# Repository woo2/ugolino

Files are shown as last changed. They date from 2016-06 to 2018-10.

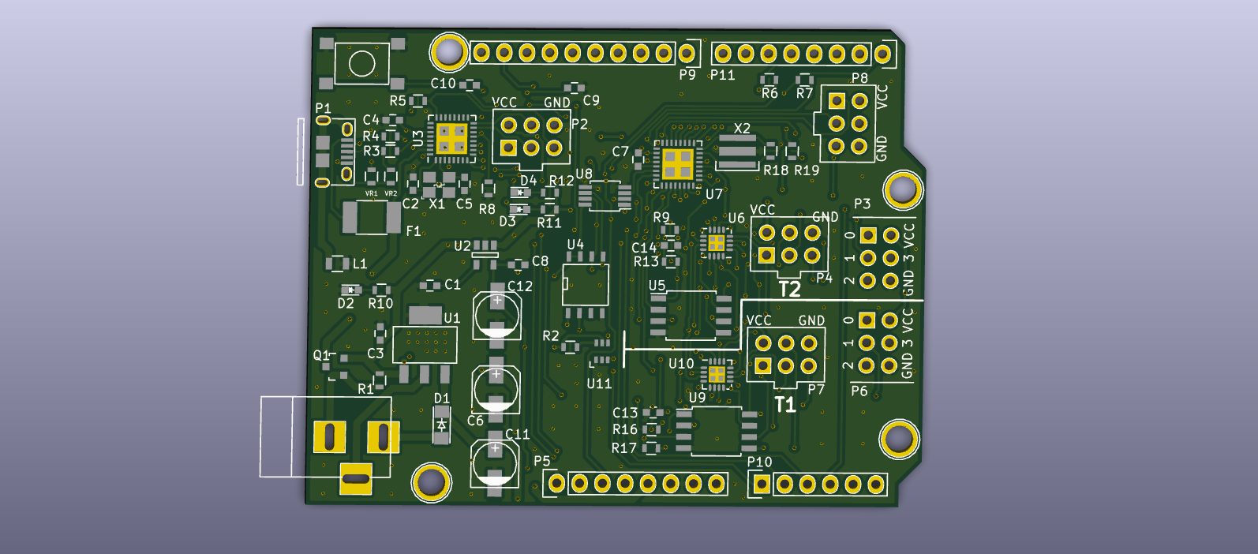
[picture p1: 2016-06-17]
hw/dev-board.png

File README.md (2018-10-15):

# The Ugolino
An Arduino compaible board based on the ATMEGA328PB that uses the secondary SPI
bus provided by the 328 to interface with 256k of SRAM. There are two aditional
AVRs on borad, both are ATTINY85 microcontrollers. The 85s share the SRAM with
the 328. The 85s' each have four GPIO pins broken out. In order to implement
this functionality, bus switches were used to multiplex the SPI bus and GPIO of
each 85.

An ATMEGA16u2 was used as a USB to serial tranceiver. Right now, support for the
328pb is limited, a patch for the pb is needed for avrdude, and the Arduino IDE
requires an extra board to be installed.

## Known Issues
* ~MISO and MOSI on the Tinys are labeled with respect to the host, where the
tiny is a slave.~(fixed)
* ~SS_328 is not connected to the SS line of the RAM.~ (fixed)
* The PCB does not yet reflect the changes marked fixed.
corrected.

## How to put code on the 328PB

1. Flash the U2:

  Running parts 1 and 2 together did not work for me. It could be that the fuses need to be written before the flash can be programmed properly. Use the same command up to the ```-U``` in part 1 for part 2.
  1. ```sudo avrdude -p m16u2 -c usbtiny -U lfuse:w:0xFF:m -U hfuse:w:0xD9:m -U efuse:w:0xF4:m -U lock:w:0x0F:m -v```
  2. ```flash:w:/home/paul/.arduino15/packages/arduino/hardware/avr/1.6.11/firmwares/atmegaxxu2/arduino-usbserial/Arduino-usbserial-atmega16u2-Uno-Rev3.hex```

2. Right now, the 328pb is not supported by avrdude. To fix this, put
[this](https://savannah.nongnu.org/bugs/?48237) snippet in your
`/etc/avrdude.conf` file. A copy of the fixed file is included. If you trust
me, run `sudo cp avrdude.conf /etc/avrdude.conf` in the root of this repo.

The Ugolino was first created as an intern project while I was working at
[Thimble.io](http://thimble.io), and I have recieved permission to publish this
work publicly.

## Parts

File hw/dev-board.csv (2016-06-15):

Reference | Quantity | Value | Footprint | Datasheet | Part Number
C1 | 1 | 470pF | Capacitors_SMD:C_0603
C10 | 1 | 100n | Capacitors_SMD:C_0603
C12 | 1 | 10uF | Capacitors_SMD:c_elec_5x5.3
C2 C5 | 2 | 15pf | Capacitors_SMD:C_0603
C4 | 1 | 1uF | Capacitors_SMD:C_0603
C11 C6 | 2 | 47uF | Capacitors_SMD:c_elec_5x5.3
C13 C14 C3 C7 C8 C9 | 6 | .1uF | Capacitors_SMD:C_0603
CON1 | 1 | BARREL_JACK | Connect:BARREL_JACK
D1 | 1 | D | GenericTransistorsFoots:SMD_Diode-1206
D2 D3 D4 | 3 | LED | LEDs:LED_0603
F1 | 1 | 500m | Resistors_SMD:R_1812
L1 | 1 | Inductor | Resistors_SMD:R_0805
P1 | 1 | USB_OTG | Spenduino_CustomFootprints:USB_Micro-B_10118194
P10 | 1 | CONN_01X06 | Pin_Headers:Pin_Header_Straight_1x06
P11 P5 | 2 | CONN_01X08 | Pin_Headers:Pin_Header_Straight_1x08
P3 P6 | 2 | CONN_02X03 | pcbfp_lib:Pin_Header_Straight_2x03_ATTINY
P2 P4 P7 P8 | 4 | CONN_02X03_ICSP | pcbfp_lib:Pin_Header_Straight_2x03_ICSP
P9 | 1 | CONN_01X10 | Pin_Headers:Pin_Header_Straight_1x10
Q1 | 1 | FDN340P | TO_SOT_Packages_SMD:SOT-23
R18 | 1 | 1M | Resistors_SMD:R_0603
R2 | 1 | 1K
R3 R4 | 2 | 22R | Resistors_SMD:R_0603
R1 R13 R16 R17 R19 R5 R9 | 7 | 10K | Resistors_SMD:R_0603
R10 R11 R12 R6 R7 R8 | 6 | 1K | Resistors_SMD:R_0603
SW1 | 1 | SW_PUSH | GenericTransistorsFoots:PTS645_Button_SMT
U1 | 1 | LM2940LD-5.0 | pcbfp_lib:SOT-223
U11 | 1 | FDG6331L | TO_SOT_Packages_SMD:SC-70-6
U2 | 1 | MIC5205 | TO_SOT_Packages_SMD:SOT-23-5
U3 | 1 | ATMEGA16U2 | Housings_DFN_QFN:QFN-32-1EP_5x5mm_Pitch0.5mm | http://www.atmel.com/Images/doc7799.pdf
U4 | 1 | 23K256 | SMD_Packages:SOIC-8-N
U5 U9 | 2 | ATTINY85-SUR | Housings_SOIC:SOIJ-8_5.3x5.3mm_Pitch1.27mm
U10 U6 | 2 | TS3A44159 | Housings_DFN_QFN:QFN-16-1EP_3x3mm_Pitch0.5mm
U7 | 1 | ATMEGA328PB-MU | Housings_DFN_QFN:QFN-32-1EP_5x5mm_Pitch0.5mm
U8 | 1 | 74LVCH1T45 | Housings_SSOP:MSOP-8_3x3mm_Pitch0.65mm
VR1 VR2 | 2 | VR | Resistors_SMD:R_0603
X1 | 1 | CRYSTAL | Spenduino_CustomFootprints:SMD_Crystal_ABM8G
X2 | 1 | RESONATOR | Spenduino_CustomFootprints:AWSCR-CV_Resonator

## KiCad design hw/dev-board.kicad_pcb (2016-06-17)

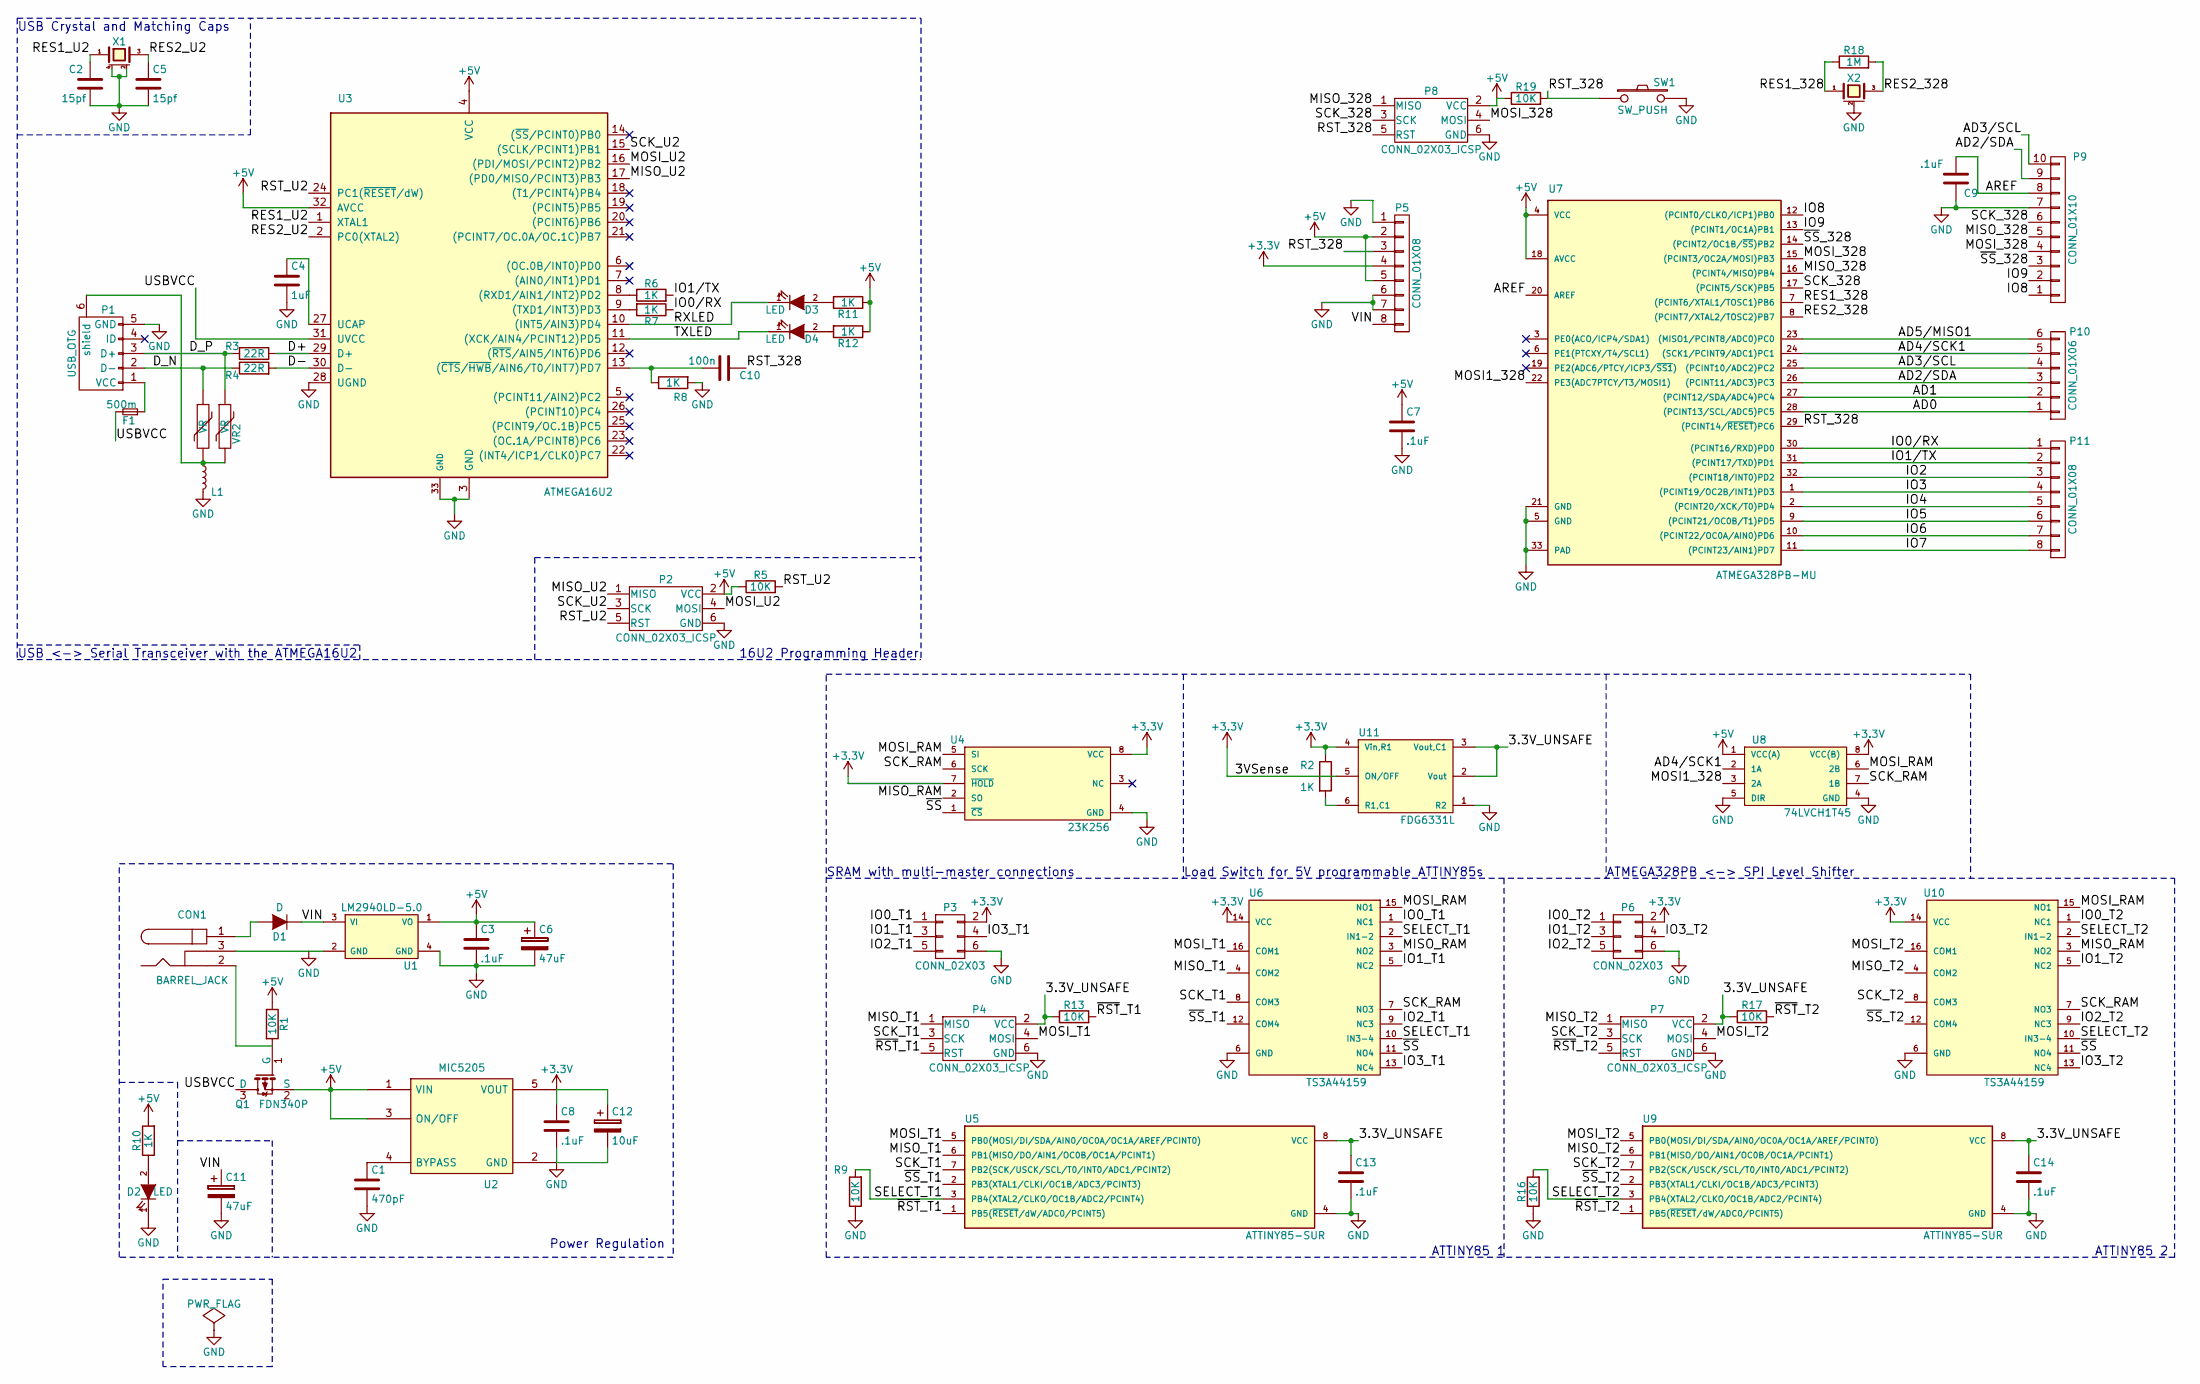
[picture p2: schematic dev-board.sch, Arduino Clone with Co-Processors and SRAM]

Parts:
C1: 470pF; C_0603
C2, C5: 15pf; C_0603
C3, C7, C8, C9, C13, C14: .1uF; C_0603
C4: 1uF; C_0603
C6, C11: 47uF; c_elec_5x5.3
C10: 100n; C_0603
C12: 10uF; c_elec_5x5.3
CON1: BARREL_JACK
D1: D; SMD_Diode-1206
D2, D3, D4: LED; LED_0603
F1: 500m; R_1812
L1: Inductor; R_0805
P1: USB_OTG; USB_Micro-B_10118194
P2, P4, P7, P8: CONN_02X03_ICSP; Pin_Header_Straight_2x03_ICSP
P3, P6: CONN_02X03; Pin_Header_Straight_2x03_ATTINY
P5, P11: CONN_01X08; Pin_Header_Straight_1x08
P9: CONN_01X10; Pin_Header_Straight_1x10
P10: CONN_01X06; Pin_Header_Straight_1x06
Q1: FDN340P; SOT-23
R1, R5, R9, R13, R16, R17, R19: 10K; R_0603
R2, R6, R7, R8, R10, R11, R12: 1K; R_0603
R3, R4: 22R; R_0603
R18: 1M; R_0603
SW1: SW_PUSH; PTS645_Button_SMT
U1: LM2940LD-5.0; SOT-223
U2: MIC5205; SOT-23-5
U3: ATMEGA16U2; QFN-32-1EP_5x5mm_Pitch0.5mm
U4: 23K256; SOIC-8-N
U5, U9: ATTINY85-SUR; SOIJ-8_5.3x5.3mm_Pitch1.27mm
U6, U10: TS3A44159; QFN-16-1EP_3x3mm_Pitch0.5mm
U7: ATMEGA328PB-MU; QFN-32-1EP_5x5mm_Pitch0.5mm
U8: 74LVCH1T45; MSOP-8_3x3mm_Pitch0.65mm
U11: FDG6331L; SC-70-6
VR1: VR; R_0603
VR2: VR; R_0603; Part Number CG0603MLC-05E1
X1: CRYSTAL; SMD_Crystal_ABM8G
X2: RESONATOR; AWSCR-CV_Resonator

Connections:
+3V3: C8.1, C12.1, P3.2, P5.4, P6.2, R2.1, U2.5 (VOUT), U4.7 (~HOLD), U4.8 (VCC), U6.14 (VCC), U8.8 (VCC(B)), U10.14 (VCC), U11.4 (Vin,R1), U11.5 (ON/OFF)
+5V: C3.1, C6.1, C7.1, P2.2 (VCC), P5.2, P5.5, P8.2 (VCC), Q1.2 (S), R1.1, R5.1, R10.2, R11.1, R12.1, R19.1, U1.1 (VO), U2.1 (VIN), U2.3 (ON/OFF), U3.4 (VCC), U3.32 (AVCC), U7.4 (VCC), U7.18 (AVCC), U8.1 (VCC(A))
/3.3V_UNSAFE: C13.1, C14.1, P4.2 (VCC), P7.2 (VCC), R13.1, R17.1, U5.8 (VCC), U9.8 (VCC), U11.2 (Vout), U11.3 (Vout,C1)
/AD0: P10.1, U7.28 ((PCINT13/SCL/ADC5)PC5)
/AD1: P10.2, U7.27 ((PCINT12/SDA/ADC4)PC4)
/AD2/SDA: P9.9, P10.3, U7.26 ((PCINT11/ADC3)PC3)
/AD3/SCL: P9.10, P10.4, U7.25 ((PCINT10/ADC2)PC2)
/AD4/SCK1: P10.5, U7.24 ((SCK1/PCINT9/ADC1)PC1), U8.2 (1A)
/AD5/MISO1: P10.6, U7.23 ((MISO1/PCINT8/ADC0)PC0)
/AREF: C9.1, P9.8, U7.20 (AREF)
/D+: R3.1, U3.29 (D+)
/D-: R4.2, U3.30 (D-)
/D_N: P1.2 (D-), R4.1, VR1.1
/D_P: P1.3 (D+), R3.2, VR2.1
/IO0/RX: P11.1, R7.1, U7.30 ((PCINT16/RXD)PD0)
/IO0_T1: P3.1, U6.1 (NC1)
/IO0_T2: P6.1, U10.1 (NC1)
/IO1/TX: P11.2, R6.2, U7.31 ((PCINT17/TXD)PD1)
/IO1_T1: P3.3, U6.5 (NC2)
/IO1_T2: P6.3, U10.5 (NC2)
/IO2: P11.3, U7.32 ((PCINT18/INT0)PD2)
/IO2_T1: P3.5, U6.9 (NC3)
/IO2_T2: P6.5, U10.9 (NC3)
/IO3: P11.4, U7.1 ((PCINT19/OC2B/INT1)PD3)
/IO3_T1: P3.4, U6.13 (NC4)
/IO3_T2: P6.4, U10.13 (NC4)
/IO4: P11.5, U7.2 ((PCINT20/XCK/T0)PD4)
/IO5: P11.6, U7.9 ((PCINT21/OC0B/T1)PD5)
/IO6: P11.7, U7.10 ((PCINT22/OC0A/AIN0)PD6)
/IO7: P11.8, U7.11 ((PCINT23/AIN1)PD7)
/IO8: P9.1, U7.12 ((PCINT0/CLKO/ICP1)PB0)
/IO9: P9.2, U7.13 ((PCINT1/OC1A)PB1)
/MISO_328: P8.1 (MISO), P9.5, U7.16 ((PCINT4/MISO)PB4)
/MISO_RAM: U4.2 (SO), U6.3 (NO2), U10.3 (NO2)
/MISO_T1: P4.1 (MISO), U5.6 (PB1(MISO/DO/AIN1/OC0B/OC1A/PCINT1)), U6.4 (COM2)
/MISO_T2: P7.1 (MISO), U9.6 (PB1(MISO/DO/AIN1/OC0B/OC1A/PCINT1)), U10.4 (COM2)
/MISO_U2: P2.1 (MISO), U3.17 ((PD0/MISO/PCINT3)PB3)
/MOSI1_328: U7.22 (PE3(ADC7PTCY/T3/MOSI1)), U8.3 (2A)
/MOSI_328: P8.4 (MOSI), P9.4, U7.15 ((PCINT3/OC2A/MOSI)PB3)
/MOSI_RAM: U4.5 (SI), U6.15 (NO1), U8.6 (2B), U10.15 (NO1)
/MOSI_T1: P4.4 (MOSI), U5.5 (PB0(MOSI/DI/SDA/AIN0/OC0A/OC1A/AREF/PCI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), U6.16 (COM1)
/MOSI_T2: P7.4 (MOSI), U9.5 (PB0(MOSI/DI/SDA/AIN0/OC0A/OC1A/AREF/PCI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), U10.16 (COM1)
/MOSI_U2: P2.4 (MOSI), U3.16 ((PDI/MOSI/PCINT2)PB2)
/RES1_328: R18.1, U7.7 ((PCINT6/XTAL1/TOSC1)PB6), X2.1
/RES1_U2: C2.1, U3.1 (XTAL1), X1.1
/RES2_328: R18.2, U7.8 ((PCINT7/XTAL2/TOSC2)PB7), X2.3
/RES2_U2: C5.1, U3.2 (PC0(XTAL2)), X1.3
/RST_328: C10.1, P5.3, P8.5 (RST), R19.2, SW1.1, U7.29 ((PCINT14/~RESET~)PC6)
/RST_U2: P2.5 (RST), R5.2, U3.24 (PC1(~RESET~/dW))
/RXLED: D3.1 (K), U3.10 ((INT5/AIN3)PD4)
/SCK_328: P8.3 (SCK), P9.6, U7.17 ((PCINT5/SCK)PB5)
/SCK_RAM: U4.6 (SCK), U6.7 (NO3), U8.7 (1B), U10.7 (NO3)
/SCK_T1: P4.3 (SCK), U5.7 (PB2(SCK/USCK/SCL/T0/INT0/ADC1/PCINT2)), U6.8 (COM3)
/SCK_T2: P7.3 (SCK), U9.7 (PB2(SCK/USCK/SCL/T0/INT0/ADC1/PCINT2)), U10.8 (COM3)
/SCK_U2: P2.3 (SCK), U3.15 ((SCLK/PCINT1)PB1)
/SELECT_T1: R9.2, U5.3 (PB4(XTAL2/CLKO/OC1B/ADC2/PCINT4)), U6.2 (IN1-2), U6.10 (IN3-4)
/SELECT_T2: R16.2, U9.3 (PB4(XTAL2/CLKO/OC1B/ADC2/PCINT4)), U10.2 (IN1-2), U10.10 (IN3-4)
/TXLED: D4.1 (K), U3.11 ((XCK/AIN4/PCINT12)PD5)
/USBVCC: F1.2, Q1.3 (D), U3.31 (UVCC)
/VIN: C11.1, D1.1 (K), P5.8, U1.3 (VI)
/~RST~_T1: P4.5 (RST), R13.2, U5.1 (PB5(~RESET~/dW/ADC0/PCINT5))
/~RST~_T2: P7.5 (RST), R17.2, U9.1 (PB5(~RESET~/dW/ADC0/PCINT5))
/~SS~: U4.1 (~CS), U6.11 (NO4), U10.11 (NO4)
/~SS~_328: P9.3, U7.14 ((PCINT2/OC1B/~SS~)PB2)
/~SS~_T1: U5.2 (PB3(XTAL1/CLKI/OC1B/ADC3/PCINT3)), U6.12 (COM4)
/~SS~_T2: U9.2 (PB3(XTAL1/CLKI/OC1B/ADC3/PCINT3)), U10.12 (COM4)
unnamed: C1.1, U2.4 (BYPASS)
unnamed: C4.1, U3.27 (UCAP)
unnamed: C10.2, R8.1, U3.13 ((~CTS~/~HWB~/AIN6/T0/INT7)PD7)
unnamed: CON1.1, D1.2 (A)
unnamed: CON1.2, Q1.1 (G), R1.2
unnamed: D2.2 (A), R10.1
unnamed: D3.2 (A), R11.2
unnamed: D4.2 (A), R12.2
unnamed: F1.1, P1.1 (VCC)
unnamed: L1.1, P1.6 (shield), VR1.2, VR2.2
unnamed: R2.2, U11.6 (R1,C1)
unnamed: R6.1, U3.8 ((RXD1/AIN1/INT2)PD2)
unnamed: R7.2, U3.9 ((TXD1/INT3)PD3)

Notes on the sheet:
Load Switch for 5V programmable ATTINY85s
SRAM with multi-master connections
ATMEGA328PB <-> SPI Level Shifter
ATTINY85 1
ATTINY85 2
Power Regulation
16U2 Programming Header
USB Crystal and Matching Caps
USB <-> Serial Transceiver with the ATMEGA16U2

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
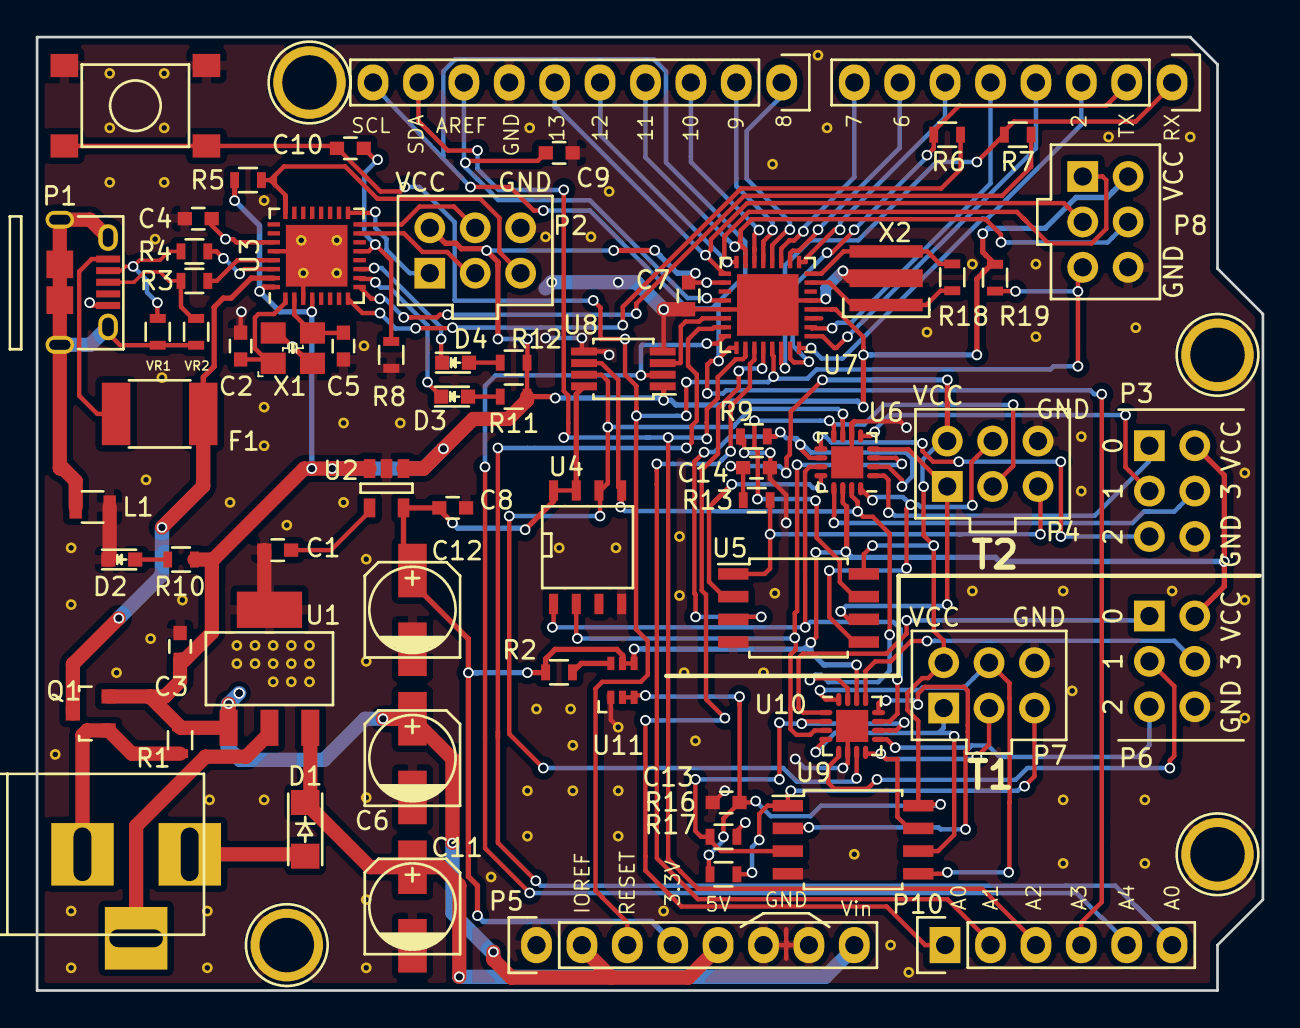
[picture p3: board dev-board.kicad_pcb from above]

Board: 2 copper layers, 68.6 x 53.3 mm, 70 parts (0 on the bottom side), 81 nets.

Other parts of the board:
P13: CONN_02X03; Arduino_1pin
P14, P22: CONN_02X03_ICSP; Arduino_1pin
P15: CONN_01X08; Arduino_1pin

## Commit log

2016-06-06 Initial kicad commit
    [dev-board.kicad_pcb, dev-board.sch]
2016-06-07 Added U2 and 328. Created ICSP Header with named pins and added gnd pad to 328.
2016-06-07 Complete Header connections and internal U2-328 connections. Power regulation and misc passives are up next.
    [dev-board.sch]
2016-06-07 Missing regulators. Xtal is fixed. 3.3v done. Power rails organized.
    [dev-board.sch]
2016-06-08 Add 5V regulator, clean up SOT-223 footprint, created 5V reg schematic symbol
    [dev-board.sch]
2016-06-08 Add schematic drawing of 328PB
    [dev-board.sch]
2016-06-08 Added ATTINY85 schematic and SRAM schematic. Added T1's programming header. Up next, T1 needs a bus switch and everything needs to be duplcated for T2.
    [dev-board.sch]
2016-06-09 Added Bus switch schematic, added a mosfet for power to ram and bs. Needed for programming. BS and ram are not 5v tolerant.
    [dev-board.sch]
2016-06-09 Switched Safe 3.3v rail for an unsafe rail. This keeps power management less complicated.
    [dev-board.sch]
2016-06-09 The schematic at this point is complete. Updated todo/readme
2016-06-09 Okay, the Schematic really is done now. Added a level shifter on 328<->SRAM
    [dev-board.sch]
2016-06-10 Removed opamp and tied 3.3v LDO switch to sense pin on DC connector.
    [dev-board.csv, dev-board.sch]
2016-06-10 Completed Footprint assignment.
    [dev-board.sch]
2016-06-10 Resolved ERC issues. There are three that remain. They are caused by KiCAD not counting passive pins that conect to a power output.
    [dev-board.sch]
2016-06-13 Add load switch schematic diagram and fix some wiring.
    [dev-board.sch]
2016-06-13 Fixed added wires to IO ports and added the load switch to the drawing. I'm not 100% certain that the present configuration will work. R1 is not given a value in the DS and there is no explicit ON/OF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
    [dev-board.sch]
2016-06-13 Label blocked off circuits and section off more areas in schemaic
    [dev-board.sch]
2016-06-13 PCB is ready for layout
    [Arduino_As_Uno.kicad_pcb, _saved_dev-board.sch, dev-board.kicad_pcb]
2016-06-13 Coarse placement of power and usb passives. All components are on board. Connectors have the correct footprint. Tinys need better placement. Final adjustments will make placing traces easier.
    [Arduino_As_Uno.kicad_pcb, _saved_dev-board.sch, dev-board.sch]
2016-06-14 Semi-Final PCB layout. Missing R1 for load switch. Pre-traces
    [Arduino_As_Uno.kicad_pcb, dev-board.sch]
2016-06-14 Pre review commit. About 25% routed. Mostly Power.
    [Arduino_As_Uno.kicad_pcb]
2016-06-14 The actual pre meeting commit.
    [Arduino_As_Uno.kicad_pcb]
2016-06-14 Fix layout.
    [Arduino_As_Uno.kicad_pcb, dev-board.csv, dev-board.sch]
2016-06-15 No major changes. PCB is 50% routed with clear vert/horiz pattern. This is just a restore point.
    [Arduino_As_Uno.kicad_pcb, dev-board.csv, dev-board.sch]
2016-06-15 end of day commit
    [Arduino_As_Uno.kicad_pcb]
2016-06-16 cleaned up many traces, especially around QFNs and in the power area. Power traces are next.
    [Arduino_As_Uno.kicad_pcb]
2016-06-16 add ground plane and stitching vias. All signals routed.
    [Arduino_As_Uno.kicad_pcb]
2016-06-16 End of day commit. 12 Unconnected nets. Needs some silikscreen.
    [Arduino_As_Uno.kicad_pcb]
2016-06-17 Completed routing.. Macrofab requires a 1.6mm clearance on traces. I made everything with 1.5mm. I'll be back.
    [Arduino_As_Uno.kicad_pcb]
2016-06-17 Completed PCB layout.
    [Arduino_As_Uno.kicad_pcb]
2016-06-17 Generated Build Files
    [Arduino_As_Uno-B.Cu.gbl, Arduino_As_Uno-B.Mask.gbs, Arduino_As_Uno-B.Paste.gbp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]
2016-06-17 Pre-production commit. Silkscreen added and some designators moved away from vias. Added BOM/picknplace
    [Arduino_As_Uno-B.Cu.gbl, Arduino_As_Uno-B.Mask.gbs, Arduino_As_Uno-B.Paste.gbp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]
2016-07-08 add 16u2 flashing instructions, rename board files
    [dev-board-B.Cu.gbl, dev-board-B.Mask.gbs, dev-board-B.Paste.gbp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]
2016-09-28 Add footprint for 4 bit level shifter.
    [dev-board.sch]
